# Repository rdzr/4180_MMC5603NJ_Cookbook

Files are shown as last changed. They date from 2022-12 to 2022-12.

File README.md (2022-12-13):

<p align="center">
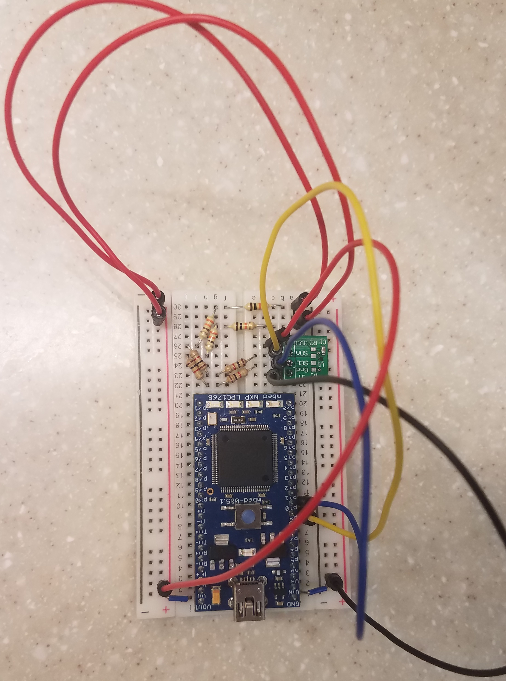
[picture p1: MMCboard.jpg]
  
</p>
This is the GitHub repository for Rhett Dozier's and Kallen Cunningham's ECE 4180 Final Project.

Video Presentation link:

[4180 Final Project MMC Breakout](https://gtvault-my.sharepoint.com/:v:/g/personal/kcunningham35_gatech_edu/EbI8oMhD1v1Ls0I9PdzCicYBiZfQq55N_jR7iZXZx02hKw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)

Video Demonstration link:

[4180 Final Project MMC Breakout Demo](https://gtvault-my.sharepoint.com/:v:/g/personal/kcunningham35_gatech_edu/Ed6LSII6g3NLusoBpMuMsVsBOc0XTfcwy2nOBlXwRSeERA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)
# 4180_MMC5603NJ_Cookbook
The MMC5603NJ is an ultra-small monolithic integrated 3-axis AMR magnetic sensor. It uses an I2C interface with compatility for I3C interfacing.
This repository serves as a wiki page for our magnetometer breakout boards that feature it as the primary piece for our ECE 4180 final project.

The breakout board was designed by Kallen Cunningham in Altium Designer with part models from Ultra Librarian. Prototype boards were manufactured by JLCPCB. The library and demo code was developed by Rhett Dozier in Mbed's Cloud Compiler.
# Table of Contents
* [Chip overview](#chip-overview)

* [Breakout board overview](#breakout-board-overview)

* [Parts needed](#parts-needed)

* [File Contents](#file-contents)

* [Usage examples](#usage-examples)

# Chip Overview

The MMC5603NJ is an ultra small (0.8 x 0.8 x 0.4 mm!) BGA package magnetometer chip that uses I2C interfacing to measure magnetic fields in the form of X, Y, and Z outputs.
The chip self-degausses and has on-board SET and RESETs. The magnetometer has a wide range of single-input DC power, ranging from 1.2 to 3.6 volts, and
the sampling rate of the chip automatically scales based on the power input.

The main feature of the chip is the ability to read the XYZ vectors by detecting the vector offsets of magneto-resistant wafers within the chip whenever they're
disturbed by an external magnetic field. Of course, a very strong magnetic field can cause issues with the measurements by distorting these wafers to the point they
can't go back to their default position, which is why the MEMSIC magnetic sensor on the chip has a magnetic strap that resets the wafers with a high current magnetic pulse.

For the XYZ vector measurements, the device has 3 modes of output: 20-bit, 18-bit, and 16-bit. All 3 modes use the respective out0 and out1 channels which are each 8 bits,
but the 18 and 20 bit modes use an additional out2 channel. Specifically, the 18-bit measurement mode uses the 2 MSBs and the 20-bit uses the 4 MSBs of the channel with the
remaining LSBs going unused. There is also an 8-bit TOut channel that lets you measure the operating temperature of the chip as a char value, with each bit equaling ~0.8 C.

The other channels that exist are Status1, ODR (output data rate), Internal Control 0, 1, and 2, Selftest values for the X, Y, and Z vectors, 
as well as selftest thresholds. Finally, there is a product ID address that should always transmit the value 0x10 or 16.

# Breakout Board Overview
<p align="center">
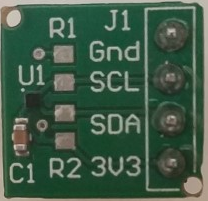
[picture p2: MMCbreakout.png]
  
</p>
The breakout board includes 4 labeled pins (Vcc, Gnd, SDA, SCL) and pads for the MMC5603NJ chip, power filtering capacitor, and I2C pull-up resistors. Also included in the repository are Gerber/NC Drill and BOM/Pick and Place outputs confirmed to work with JLCPCB fabrication and PCB assembly services. It is reccomended that all boards produced include the capacitor soldered on, but the pull-up resistors can be left off and external resistors used instead to lower costs.

# Parts needed
* MMC5603NJ: https://www.digikey.com/en/products/detail/memsic-inc/MMC5603NJ/10452796
* Mbed LPC1768: https://www.sparkfun.com/products/9564
* M/M Jumper Wires: https://www.sparkfun.com/products/12795
* Resistors (various, needs to total up to 2.7k Ohms): https://www.sparkfun.com/products/10969

# File Contents
The header file MMC5603NJ.h and C++ file MMC5603NJ.cpp are the components necessary to the import the MMC5603NJ's capabilities to an Mbed project.
Including these in the Mbed's directory as well as an include and a class constructor using the appropriate I2C sda and scl pin lines allows you to interact with
the MMC5603NJ breakout board. For example,

```
#include "mbed.h"
#include "MMC5603NJ.h"

MMC5603NJ mmc(p9, p10);
```
Allows you to create a MMC5603NJ object for the Mbed LPC1768, using pin 9 as the sda and pin 10 as the scl.
# Usage Examples
Included with the wiki page is MMCDemo.cpp, a file meant to be ran on the Mbed to demonstrate various capabilities of the MMC5603NJ breakout board. It contains the following functions:

setRate(char rate) to change the output data rate, or ODR, for the sampling speed of continuous measurement mode.

testContMode() and contSampleForever() to test the MMC's continuous measurement mode

testSingleSampleModes() and singleSampleForever() to test the MMC's single-measurement mode

testTemperature() to test the temperature measurement of the MMC

testPID() as a way to check the device's product ID. Useful for debugging the SDA/SCL clock lines since it should always return 0x10, or 16 in decimal form.

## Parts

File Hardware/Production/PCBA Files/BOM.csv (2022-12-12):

Comment | Designator | Footprint | LibRef
CL10A225KP8NNNC | C1 | CAP 0603 | CL10A225KP8NNNC
Header 0.1" 4P | J1 | 0.1" Header 4P | Header 0.1" 4P
RC0805JR-072K7L | R1, R2 | RES 0805 | RC0805JR-072K7L
MMC5603NJ | U1 | 4-WLP | MMC5603NJ

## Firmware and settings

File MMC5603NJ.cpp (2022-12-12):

#include "MMC5603NJ.h"
#include "mbed.h"

// This constructor class sets the "DO RESET"
// bit in INCTRL0 high in order for the chip to
// reset its magnetometer wafer. It takes
// 375 nanoseconds to occur so some padding is given
// afterwards for it to operate. The bit is automatically
// cleared by the device after the reset is completed.
MMC5603NJ::MMC5603NJ(PinName sda, PinName scl): m_i2c(sda, scl), m_addr(MMC_ADDR)
{
    char cmd[2];
    cmd[0] = MMC_INCTRL0;
    cmd[1] = 0x08;
    m_i2c.write(m_addr, cmd, 2);
    wait(0.1);
}
void MMC5603NJ::setBitRate(unsigned char rate) {
    char data[2];
    data[1] = rate;
    data[0] = MMC_ODR;
    m_i2c.write(m_addr, data, 2);
}
// Sends a signal to the MMC's INCTRL0 register
// to get its current value and performs a bitwise
// OR operation with 0b10000000, and then gets INCTRL2 and performs a
// bitwise OR with 0b00010000. Setting both of these register bits to 1 enables
// continuous measuremnt mode on the MMC chip.
void MMC5603NJ::enable() {
    continuous = true;
    char en[2];
    readRegs( MMC_INCTRL0, &en[1], 1);
    en[1] |= 0x80;
    en[0] = MMC_INCTRL0;
    m_i2c.write(m_addr, en, 2);
    readRegs(MMC_INCTRL2, &en[1], 1);
    en[1] |= 0x10;
    en[0] = MMC_INCTRL2;
    m_i2c.write(m_addr, en, 2);
}

// Sends a signal to the MMC's INCTRL0 register
// by getting its current values and then performing
// A bitwise and with 0b01111111, and similarly with
// INCTRL2 and 0b11101111 in order to set the continuous
// read bit low to disable continuous measurement mode.
void MMC5603NJ::disable(void) {
    continuous = false;
    char en[2];
    readRegs(MMC_INCTRL2, &en[1], 1);
    en[1] &= 0xEF;
    en[0] = MMC_INCTRL2;
    m_i2c.write(m_addr, en, 2);
}

// Returns the product ID.
// @returns the product ID, which should always be 0x10 in hex or 16 in decimal.
uint32_t MMC5603NJ::PID() {
    char pid = 0;
    readRegs(MMC_PID, &pid, 1);
    return (uint32_t) pid;
}

// Gets the current operating temperature of the MMC chip.
// The given formula is -75 + (0.8 * TOUT) degrees celsius.
// @returns the temperature of the chip in celsius
char MMC5603NJ::getTemp() {
    char en[2];
    readRegs( MMC_INCTRL0, &en[1], 1);
    // Forcing this register to exactly 0b00000010 is terrible coding practice
    // and it should be a bitwise OR with 0x10, but that doesn't work.
    // Doing as such causes very strange undefined behavior to occur.
    en[1] = 0x02;
    en[0] = MMC_INCTRL0;
    m_i2c.write(m_addr, en, 2);
    char status = 0;
    while ((status >> 7 == 0)) {
        readRegs(MMC_STATUS1, &status, 1);
        wait(0.2);
        m_i2c.write(m_addr, en, 2);
    }
    char res[1];
    readRegs(MMC_TOUT, res, 1);
    unsigned char ures = (unsigned char)res[0];
    float out = (float)ures;
    out = (out * 0.8) - 75;
    return out;
}

// Gets the most recently sampled x value.
float MMC5603NJ::getX() {
    int32_t xVal = getMagAxis(MMC_XOUT0) - 524288;
    x = ((float)xVal/(float)16384);
    return x;
}
// Gets the most recently sampled y value.
float MMC5603NJ::getY() {
    int yVal = getMagAxis(MMC_YOUT0) - 524288;
    y = ((float)yVal/(float)16384);
    return y;
}
// Gets the most recently sampled z value.
float MMC5603NJ::getZ() {
    int zVal = getMagAxis(MMC_ZOUT0) - 524288;
    z = ((float)zVal/(float)16384);
    return z;
}

// Samples all three coordinate axes at once and stores in the x/y/z floats.
void MMC5603NJ::getAxis() {
    int32_t t[3];
    char res[9];
    if(continuous) {
        
        readRegs(MMC_XOUT0, res, 9);
        t[0] = (res[0] << 12) | (res[1] << 4) | (res[6] >> 4);
        t[1] = (res[2] << 12) | (res[3] << 4) | (res[7] >> 4);
        t[2] = (res[4] << 12) | (res[5] << 4) | (res[8] >> 4);
        t[0] -= 524288;
        t[1] -= 524288;
        t[2] -= 524288;
        x = ((float) t[0])/((float) 16384);
        y = ((float) t[1])/((float) 16384);
        z = ((float) t[2])/((float) 16384);
    } else {
        t[0] = getMagAxis(MMC_XOUT0) - 524288;
        t[1] = getMagAxis(MMC_YOUT0) - 524288;
        t[2] = getMagAxis(MMC_ZOUT0) - 524288;
        x = ((float) t[0])/((float) 16384);
        y = ((float) t[1])/((float) 16384);
        z = ((float) t[2])/((float) 16384);
    }
}

// Wrapper function for the i2c superclass's read function.
// @param addr The address being read
// @param data Pointer to a char value
void MMC5603NJ::readRegs(int addr, char * data, int len)
{
    char cmd[1];
    cmd[0] = addr;
    m_i2c.write( m_addr, cmd, 1, true);
    m_i2c.read( m_addr, (char *) data, len);
    return;
}

// Gets a specific axis value based on the coordinate
// of the first OUT0 bit.
// Technically there are 3 possible output modes:
// 16 bit, 18 bit, and 20 bit.
// However, given a 3.3V power supply from an mbed
// this should always output in 20 bit mode.
// The only real difference between the modes
// is that the 16 and 18 bit modes have less decimal
// accuracy compared to the 20 bit mode.
// @param addr the specified address being sampled
// @returns the 20-bit integer value for X, Y, or Z.
int32_t MMC5603NJ::getMagAxis(char addr) {
    char en[2];
    readRegs( MMC_INCTRL0, &en[1], 1);
    en[1] = 0x01;
    en[0] = MMC_INCTRL0;
    m_i2c.write(m_addr, en, 2);
    char status = 0;
    while ((status & 0x40) == 0) {
        readRegs(MMC_STATUS1, &status, 1);
    }
    int32_t acc;
    char res[7];
    readRegs(addr, res, 7);
    acc = (res[0] << 12) | (res[1] << 4) | (res[6] >> 4);
    return acc;
}

// Wrapper function for the i2c superclass's write function.
// @param data Pointer to an char array of X length, where data[0] is the
// register that is being written to.
// @param len How many bytes are being written, excluding the specified register
void MMC5603NJ::writeRegs(char * data, int len) {
    m_i2c.write(m_addr, (char *)data, len);
}

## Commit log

2022-11-30 header file
    Added header file for MMC. Extension of the MotionSensor header file, which is provided by ARM to be used as a standardized base for XYZ-based coordinate measurement devices.
2022-12-12 Added Hardware Source Files
    Altium Source Files and Gerber/Pick Place Outputs
    [BOM.csv, MMC5603_Breakout.PrjPcb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]
2022-12-12 Added Board Overview
    Added description of board/included files.
